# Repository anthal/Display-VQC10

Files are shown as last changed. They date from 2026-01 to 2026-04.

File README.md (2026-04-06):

# VQC10
DDR (WF) Punkt-Matrix-LED-Display VQC10 (Leiterplatte und Code)

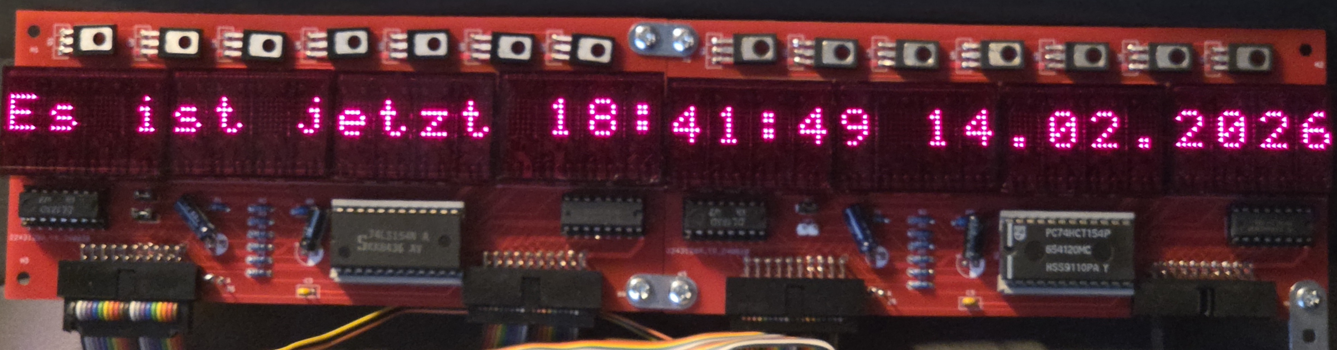
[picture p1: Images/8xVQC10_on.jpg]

Version 1

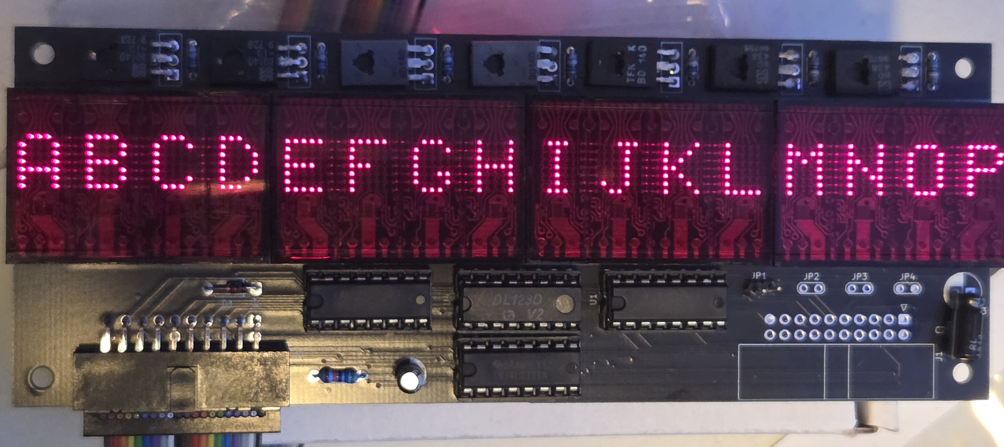
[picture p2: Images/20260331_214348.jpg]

Version 2

## Leiterplatte Version 2
### Platine
* Farbe der Platine V.1 auf den Bildern: rot
* Farbe der Platine V.2 auf den Bildern: schwarz
* KiCAD 9 Projekt
* Die Platinen sind nebeneinander anreihbar und es können bis zu 4 Stück kaskadiert werden.
* Ab der 2. Platine geht es mit Flachbandkabel zur nächsten Platine. 
* Jede Platine wird über eine eigene Leitung (SD4-SD7) aktiviert. Die Auswahl erfolgt über die 4 Jumper.

### Halbleiterbauelemente
* 4 x VQC 10 (4-Digit-Punkt-Matrix-LED-Displays) 
* 3 x 74LS138 (1-aus-8 Dekoder für Zeilen und 1-aus-16 Dekoder für Digits)
* 1 x 74LS123 (Schutzschaltung)
* 7 x BD140 (Zeilentreiber)

### Anschlüsse Leiterplatte Version 1
**An 20 pol. Steckerleiste:**
* ZD0 - ZD2 (3): Zeilendecoder (U1, 74HCT138)
* SD0 - SD3 (4): Stellendecoder (U2, U3, 2x 74HCT138)
* SD4 - SD7 (4): Selektierung der Stellendecoder über Jumper (Low-Aktiv)
* D1-D5 (5): Daten (Zeilen)

**Belegung der Anschlüsse:**
| Pin | Belegung | Raspberry Pi Pico | LC80ex | Pin LC80-Userport |
|-----|---|---|---|---|
| 1 | +5 V | +5 V | +5 V | 26 |
| 2 | +5 V | +5 V | +5 V | 25 |
| 3 | SD0 | GP20 | PB0 | 16 |
| 4 | ZD0 | GP15 | PA0 | 21 |
| 5 | SD1 | GP19 | PB1 | 18 |
| 6 | ZD1 | GP14 | PA1 | 19 |
| 7 | SD2 | GP18 | PB2 | 20 |
| 8 | ZD2 | GP12 | PA2 | 17 |
| 9 | SD3 | GP17 | PB3 | 22 |
| 10  | D1 | GP28 | PA3 | 7 |
| 11  | SD4 | GP16 | (Masse)| - |
| 12  | D2 | GP27 | PA4 | 9 |
| 13  | SD5 | GP10 | (Masse)| - |
| 14  | D3 | GP26 | PA5 | 11 |
| 15  | SD6 | GP9 | (Masse)| - |
| 16  | D4 | GP22 | PA6 | 13 |
| 17  | SD7 | GP8 | (Masse)| - |
| 18  | D5 | GP21 | PA7 | 15 |
| 19  | Masse | Masse | Masse  | 1 |
| 20  | Masse | Masse | Masse  | 2 |

### Selektion der 4 Leiterplatten
SD4-7 müssen zur Selektierung Low und der jeweilige Jumper geschlossen sein:
| Leiterplatte | Jumper | Pin (J1/J2) | Belegung | Port-Pin (Raspberry Pi Pico) |
|---|-----|----|-----|---|
| 1 | JP1 | 11 | SD4 | GP16 |
| 2 | JP2 | 13 | SD5 | GP10 |
| 3 | JP3 | 15 | SD6 | GP9 |
| 4 | JP4 | 17 | SD7 | GP8 |

**Leiterplatte 1:** 
* Jumper JP1 geschlossen
* Jumper JP2 geöffnet
* Jumper JP3 geöffnet
* Jumper JP4 geöffnet

**Leiterplatte 2:**
* Jumper JP1 geöffnet
* Jumper JP2 geschlossen
* Jumper JP3 geöffnet
* Jumper JP4 geöffnet

**Leiterplatte 3:**
* Jumper JP1 geöffnet
* Jumper JP2 geöffnet
* Jumper JP3 geschlossen
* Jumper JP4 geöffnet

**Leiterplatte 4:**
* Jumper JP1 geöffnet
* Jumper JP2 geöffnet
* Jumper JP3 geöffnet
* Jumper JP4 geschlossen

## Literatur
* Datenblatt
* Schaltungen aus der rfe

## Simulation
* Simulation von 1x VQC10 mit Z80 unter SimulIDE
* https://simulide.com/
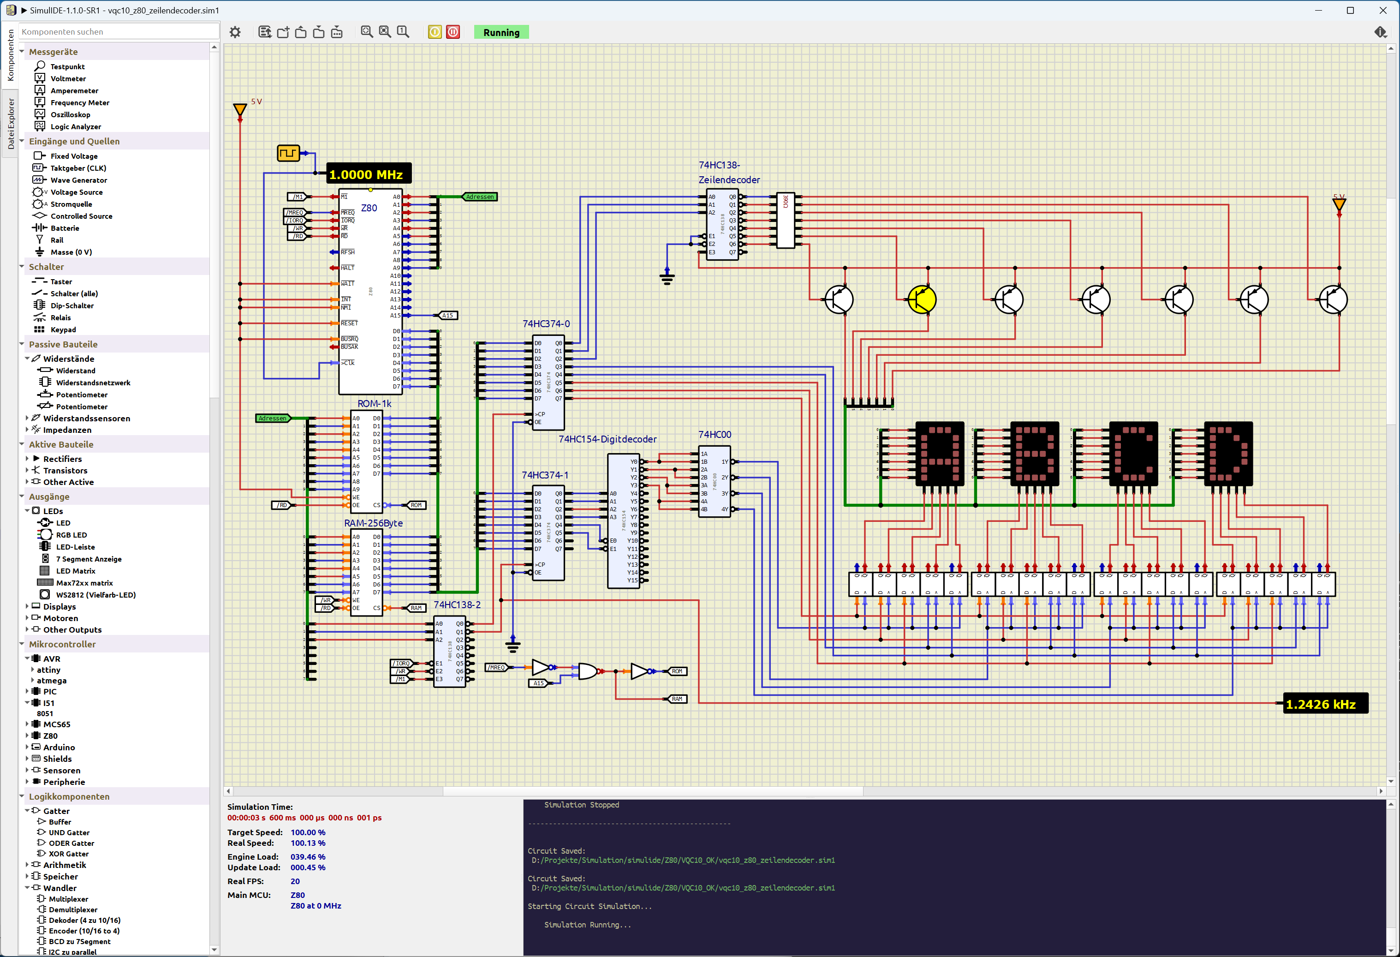
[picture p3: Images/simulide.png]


## Software
### Arduino Code
* Für den Raspberry Pi Pico
* auf Basis von https://github.com/versioduo/VQC10
* Vor Compilierung Example Datei und Files aus scr Verzeichnis in ein gemeinsames Verzeichnis verschieben

### Micropython Code
* Für den Raspberry Pi Pico

### Z80-Assembler
#### aZ80/RC2016-Computer
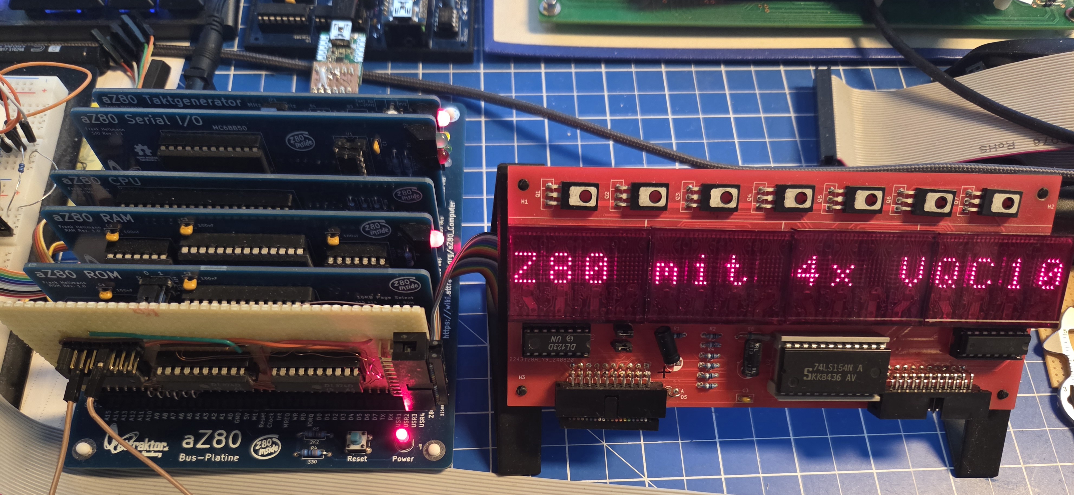
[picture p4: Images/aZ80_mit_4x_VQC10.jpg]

4x VQC10 am aZ80 Computer

Benutzte Entwicklungssoftware:
* "Small Computer-Monitor"
* https://smallcomputercentral.com/small-computer-monitor/

#### LC80ex
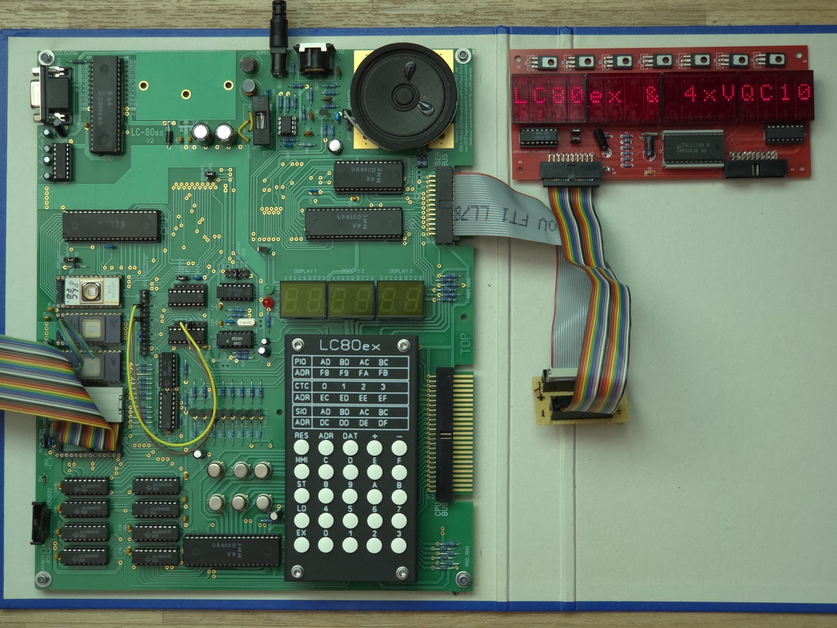
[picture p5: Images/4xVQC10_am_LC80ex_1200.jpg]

Test mit dem Nachbau des DDR-Platinen Computers LC80 

#### Z1013
ToDo

## Gehäuse
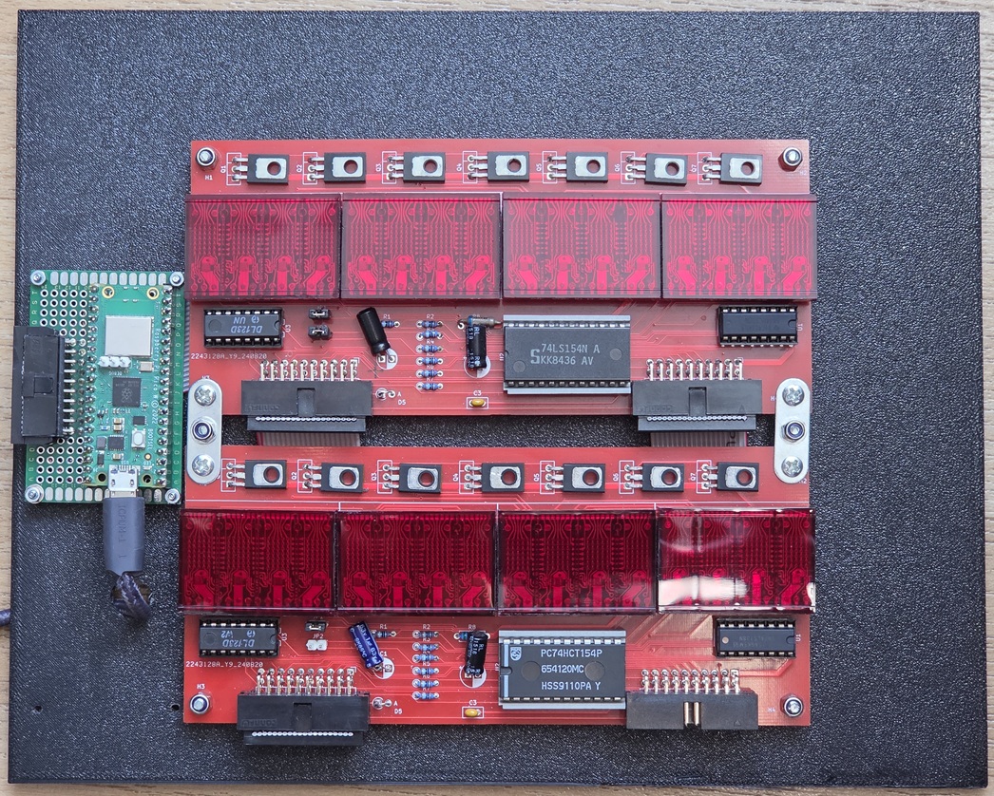
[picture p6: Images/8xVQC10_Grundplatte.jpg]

Grundplatte für IKEA Bilderrahmmen "VÄSTANHED 20x25 cm" mit Leiterplatten der Version 1
* STL Datei für 3D-Druck: "Gehäuse/2xVQC10_Grundplatte1.stl"

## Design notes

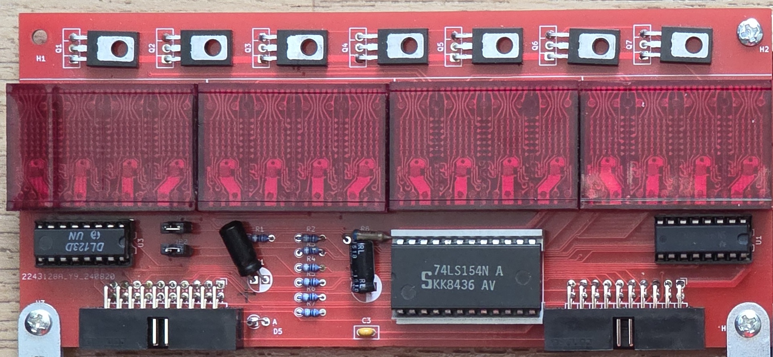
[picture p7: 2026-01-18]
Images/4xVQC10_off.jpg

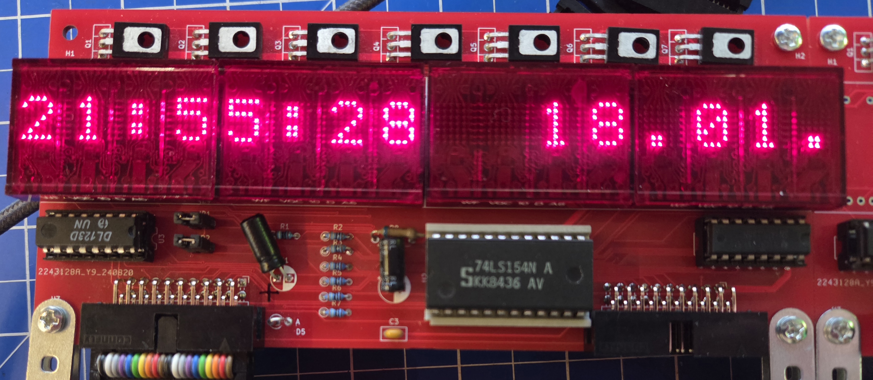
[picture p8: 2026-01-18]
Images/4xVQC10_on.jpg

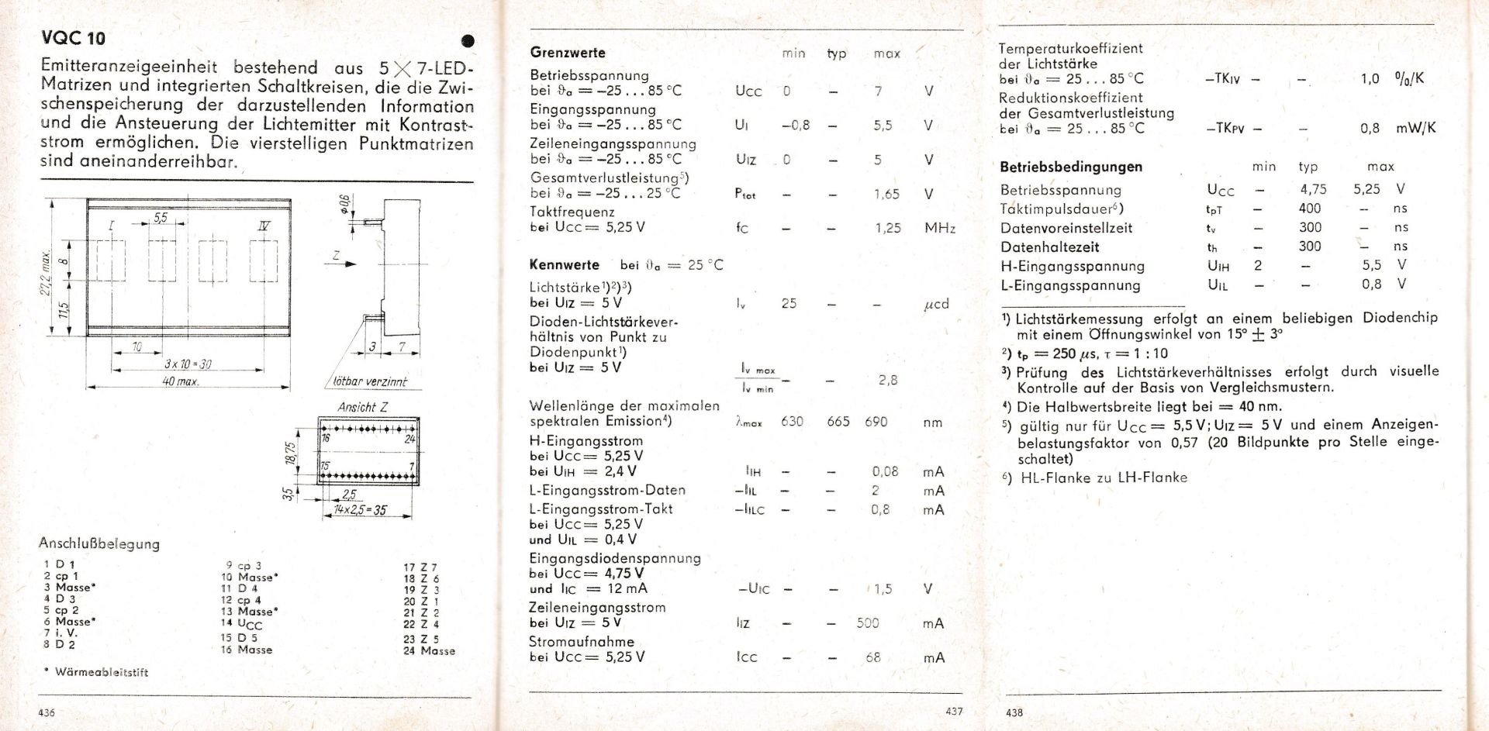
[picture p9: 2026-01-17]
Literatur/Datenblatt_VQC10.jpeg

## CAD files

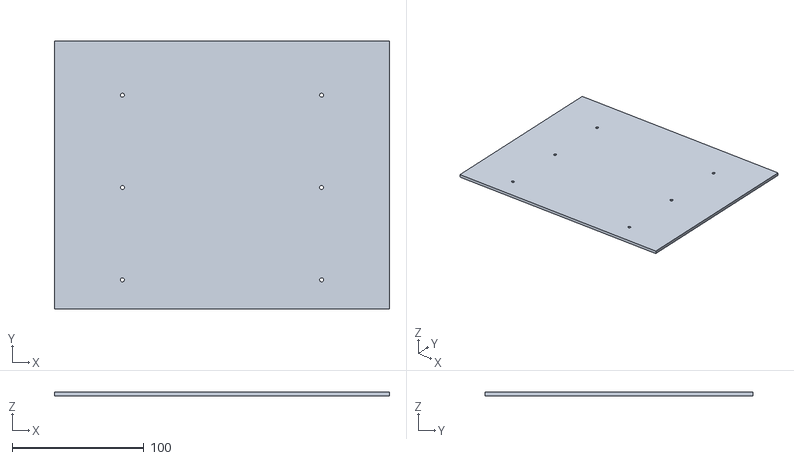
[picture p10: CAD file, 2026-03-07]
Gehäuse/2xVQC10 Grundplatte1.stl
254.0 x 203.0 x 3.00

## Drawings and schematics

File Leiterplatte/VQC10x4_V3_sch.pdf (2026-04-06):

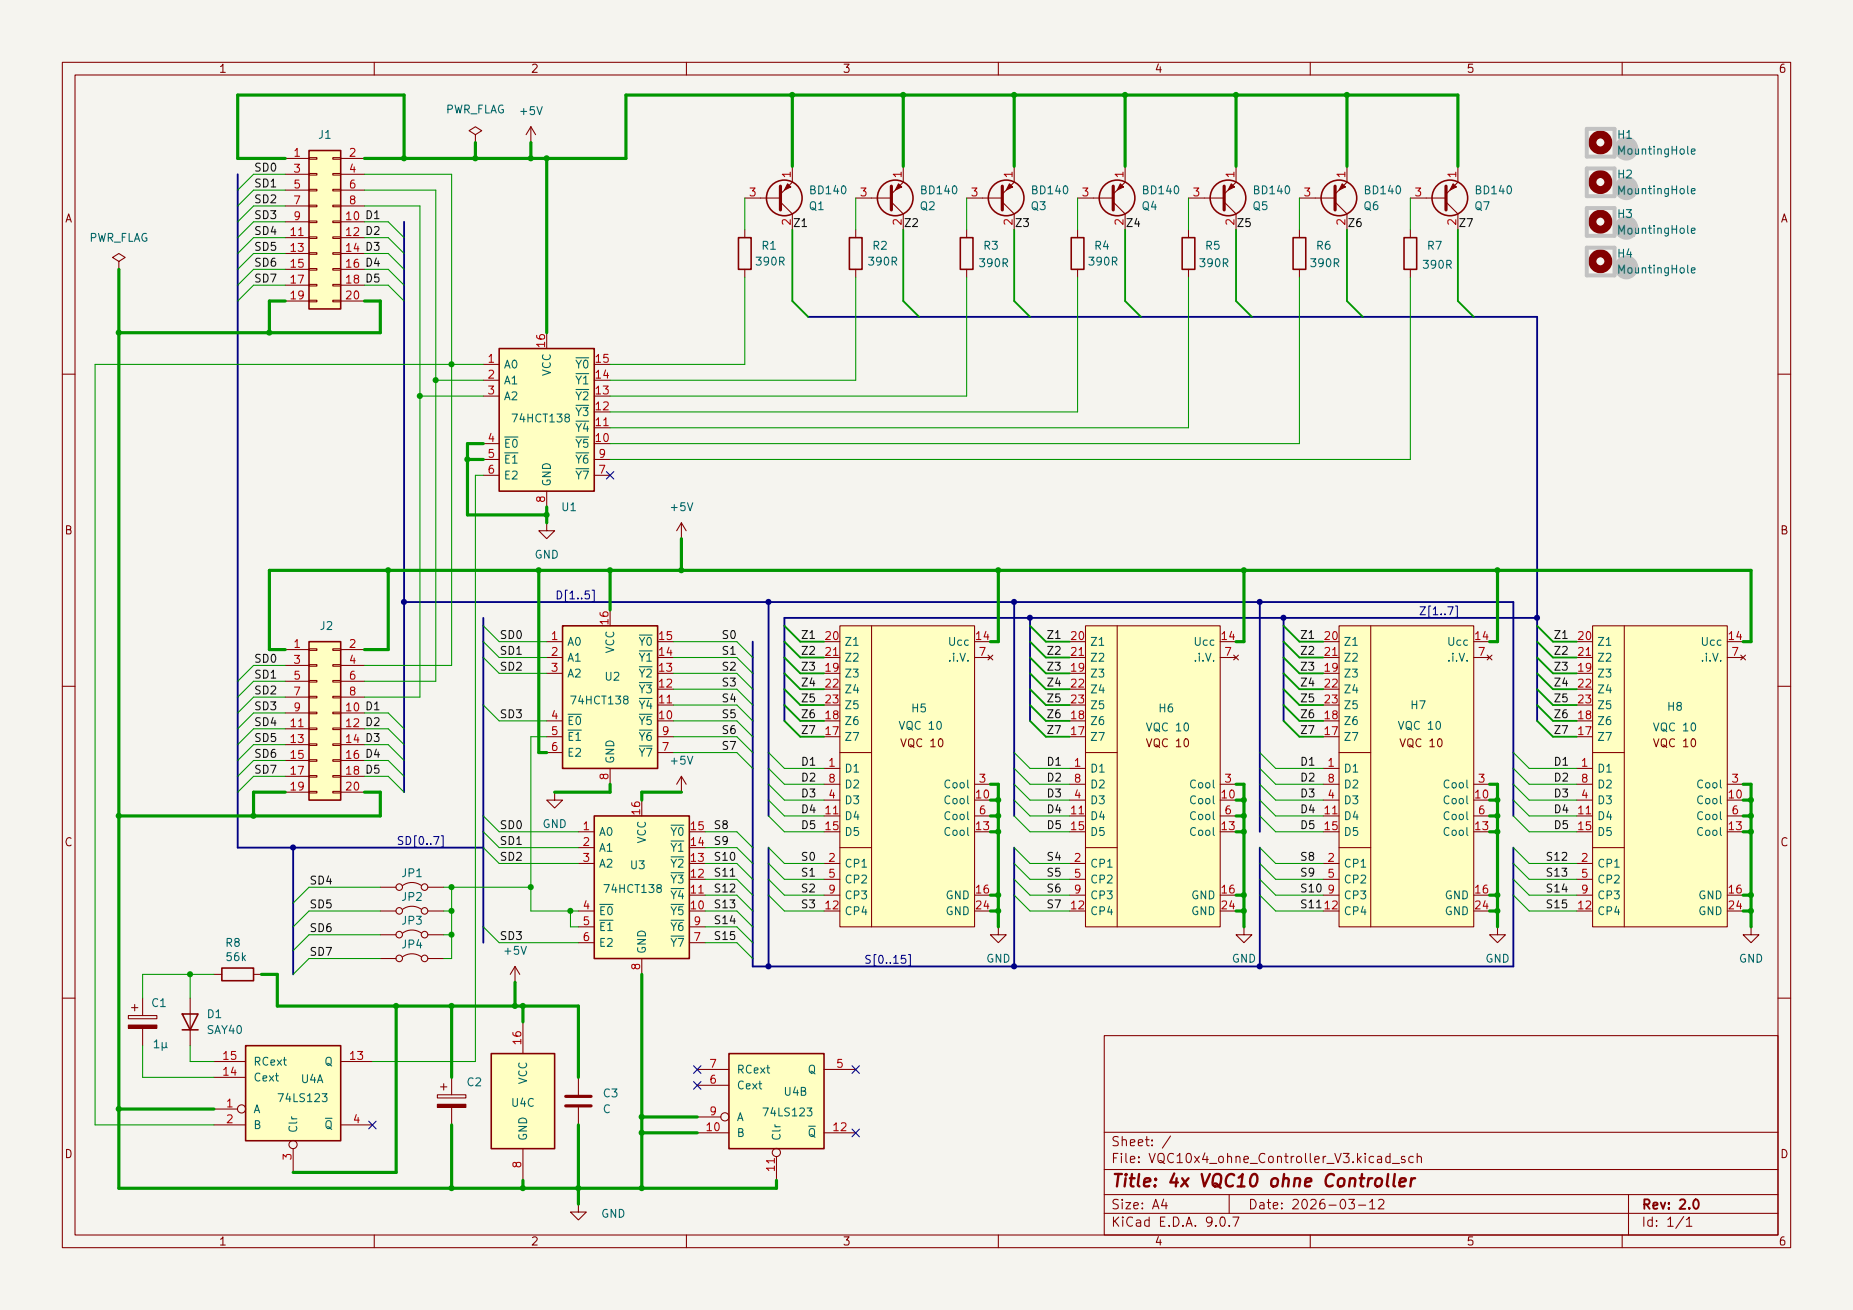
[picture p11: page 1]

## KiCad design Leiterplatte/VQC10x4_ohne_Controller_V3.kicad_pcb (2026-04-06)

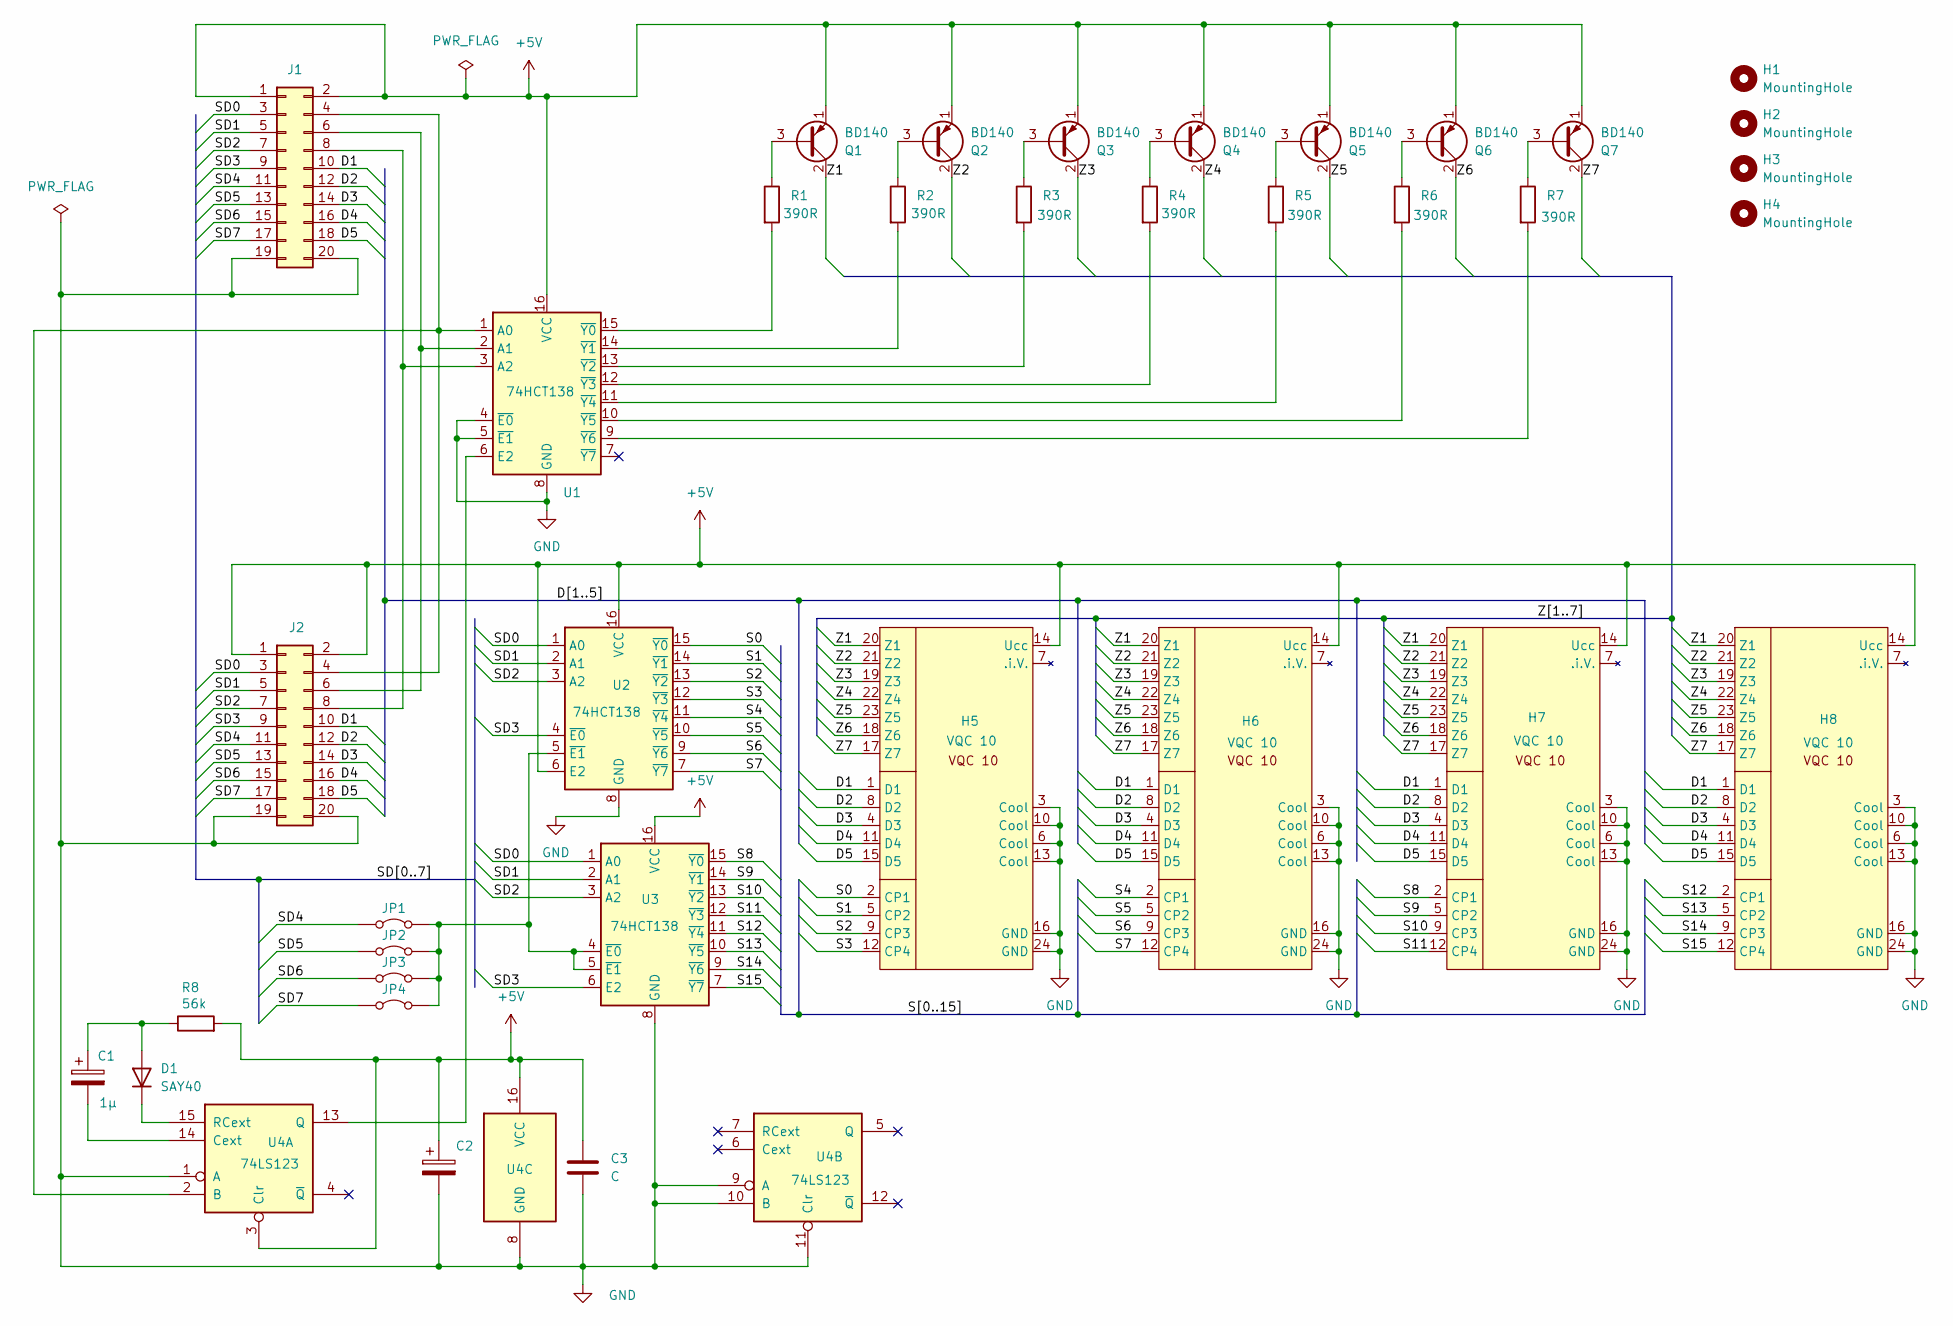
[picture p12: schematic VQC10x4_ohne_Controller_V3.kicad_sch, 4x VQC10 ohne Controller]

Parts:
C1: 1µ; CP_Radial_D5.0mm_P2.50mm
C2: C_Polarized; CP_Radial_D6.3mm_P2.50mm
C3: C; C_Disc_D5.0mm_W2.5mm_P2.50mm
D1: SAY40; D_A-405_P7.62mm_Horizontal
H1, H2, H3, H4: MountingHole; MountingHole_3.2mm_M3
H5, H6, H7, H8: VQC 10; VQC10
J1, J2: Conn_02x10_Odd_Even; IDC-Header_2x10_P2.54mm_Horizontal
JP1, JP2, JP3, JP4: Jumper_2_Bridged; TestPoint_2Pads_Pitch2.54mm_Drill0.8mm
Q1, Q2, Q3, Q4, Q5, Q6, Q7: BD140; TO-126-3_Vertical
R1, R2, R3, R4, R5, R6, R7: 390R; R_Axial_DIN0204_L3.6mm_D1.6mm_P5.08mm_Horizontal
R8: 56k; R_Axial_DIN0207_L6.3mm_D2.5mm_P7.62mm_Horizontal
U1, U2, U3: 74HCT138; DIP-16_W7.62mm_LongPads
U4: 74LS123; DIP-16_W7.62mm_LongPads

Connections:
+5V: C2.1, C3.1, H5.14 (Ucc), H6.14 (Ucc), H7.14 (Ucc), H8.14 (Ucc), J1.1, J1.2, J2.1, J2.2, Q1.1 (E), Q2.1 (E), Q3.1 (E), Q4.1 (E), Q5.1 (E), Q6.1 (E), Q7.1 (E), R8.2, U1.16 (VCC), U2.6 (E2), U2.16 (VCC), U3.16 (VCC), U4.3 (Clr), U4.16 (VCC)
/D1: H5.1 (D1), H6.1 (D1), H7.1 (D1), H8.1 (D1), J1.10, J2.10
/D2: H5.8 (D2), H6.8 (D2), H7.8 (D2), H8.8 (D2), J1.12, J2.12
/D3: H5.4 (D3), H6.4 (D3), H7.4 (D3), H8.4 (D3), J1.14, J2.14
/D4: H5.11 (D4), H6.11 (D4), H7.11 (D4), H8.11 (D4), J1.16, J2.16
/D5: H5.15 (D5), H6.15 (D5), H7.15 (D5), H8.15 (D5), J1.18, J2.18
/S0: H5.2 (CP1), U2.15 (~Y0)
/S1: H5.5 (CP2), U2.14 (~Y1)
/S2: H5.9 (CP3), U2.13 (~Y2)
/S3: H5.12 (CP4), U2.12 (~Y3)
/S4: H6.2 (CP1), U2.11 (~Y4)
/S5: H6.5 (CP2), U2.10 (~Y5)
/S6: H6.9 (CP3), U2.9 (~Y6)
/S7: H6.12 (CP4), U2.7 (~Y7)
/S8: H7.2 (CP1), U3.15 (~Y0)
/S9: H7.5 (CP2), U3.14 (~Y1)
/S10: H7.9 (CP3), U3.13 (~Y2)
/S11: H7.12 (CP4), U3.12 (~Y3)
/S12: H8.2 (CP1), U3.11 (~Y4)
/S13: H8.5 (CP2), U3.10 (~Y5)
/S14: H8.9 (CP3), U3.9 (~Y6)
/S15: H8.12 (CP4), U3.7 (~Y7)
/SD0: J1.3, J2.3, U2.1 (A0), U3.1 (A0)
/SD1: J1.5, J2.5, U2.2 (A1), U3.2 (A1)
/SD2: J1.7, J2.7, U2.3 (A2), U3.3 (A2)
/SD3: J1.9, J2.9, U2.4 (~E0), U3.6 (E2)
/SD4: J1.11, J2.11, JP1.1 (A)
/SD5: J1.13, J2.13, JP2.1 (A)
/SD6: J1.15, J2.15, JP3.1 (A)
/SD7: J1.17, J2.17, JP4.1 (A)
/Z1: H5.20 (Z1), H6.20 (Z1), H7.20 (Z1), H8.20 (Z1), Q1.2 (C)
/Z2: H5.21 (Z2), H6.21 (Z2), H7.21 (Z2), H8.21 (Z2), Q2.2 (C)
/Z3: H5.19 (Z3), H6.19 (Z3), H7.19 (Z3), H8.19 (Z3), Q3.2 (C)
/Z4: H5.22 (Z4), H6.22 (Z4), H7.22 (Z4), H8.22 (Z4), Q4.2 (C)
/Z5: H5.23 (Z5), H6.23 (Z5), H7.23 (Z5), H8.23 (Z5), Q5.2 (C)
/Z6: H5.18 (Z6), H6.18 (Z6), H7.18 (Z6), H8.18 (Z6), Q6.2 (C)
/Z7: H5.17 (Z7), H6.17 (Z7), H7.17 (Z7), H8.17 (Z7), Q7.2 (C)
GND: C2.2, C3.2, H5.3 (Cool), H5.6 (Cool), H5.10 (Cool), H5.13 (Cool), H5.16 (GND), H5.24 (GND), H6.3 (Cool), H6.6 (Cool), H6.10 (Cool), H6.13 (Cool), H6.16 (GND), H6.24 (GND), H7.3 (Cool), H7.6 (Cool), H7.10 (Cool), H7.13 (Cool), H7.16 (GND), H7.24 (GND), H8.3 (Cool), H8.6 (Cool), H8.10 (Cool), H8.13 (Cool), H8.16 (GND), H8.24 (GND), J1.19, J1.20, J2.19, J2.20, U1.4 (~E0), U1.5 (~E1), U1.8 (GND), U2.8 (GND), U3.8 (GND), U4.1 (A), U4.8 (GND), U4.9 (A), U4.10 (B), U4.11 (Clr)
unnamed: C1.1, D1.2 (A), R8.1
unnamed: D1.1 (K), U4.15 (RCext)
unnamed: J1.4, J2.4, U1.1 (A0), U4.2 (B)
unnamed: J1.6, J2.6, U1.2 (A1)
unnamed: J1.8, J2.8, U1.3 (A2)
unnamed: JP1.2 (B), JP2.2 (B), JP3.2 (B), JP4.2 (B), U2.5 (~E1), U3.4 (~E0), U3.5 (~E1)
unnamed: Q1.3 (B), R1.1
unnamed: Q2.3 (B), R2.1
unnamed: Q3.3 (B), R3.1
unnamed: Q4.3 (B), R4.1
unnamed: Q5.3 (B), R5.1
unnamed: Q6.3 (B), R6.1
unnamed: Q7.3 (B), R7.1
unnamed: U1.6 (E2), U4.13 (Q)
unnamed: R1.2, U1.15 (~Y0)
unnamed: R2.2, U1.14 (~Y1)
unnamed: R3.2, U1.13 (~Y2)
unnamed: R4.2, U1.12 (~Y3)
unnamed: R5.2, U1.11 (~Y4)
unnamed: R6.2, U1.10 (~Y5)
unnamed: R7.2, U1.9 (~Y6)
unnamed: C1.2, U4.14 (Cext)

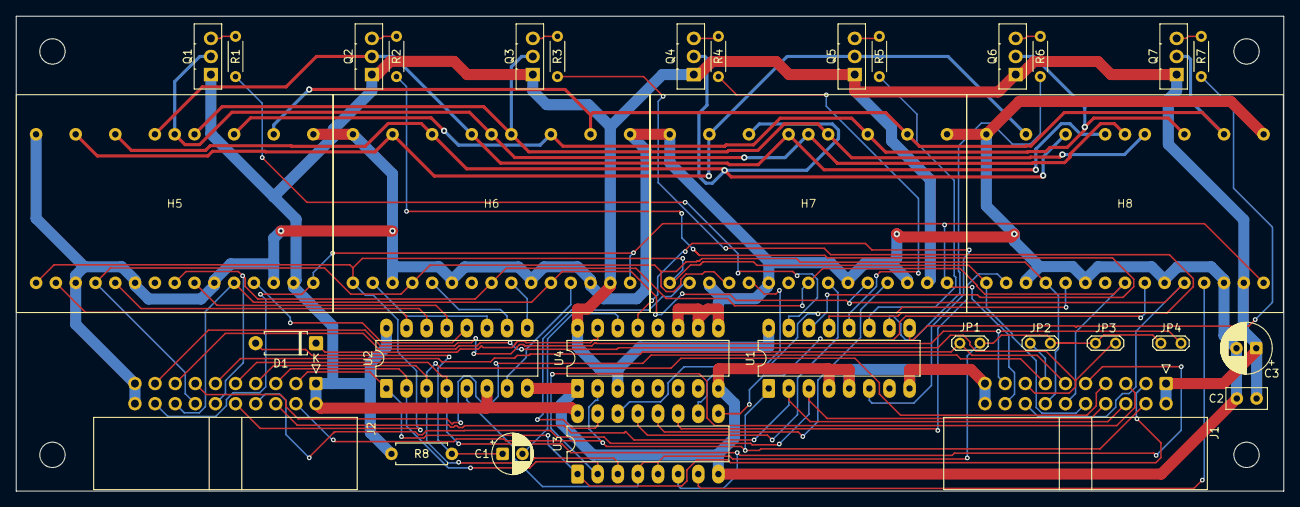
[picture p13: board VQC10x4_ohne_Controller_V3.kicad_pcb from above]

Board: 2 copper layers, 160.0 x 59.9 mm, 37 parts (0 on the bottom side), 60 nets.

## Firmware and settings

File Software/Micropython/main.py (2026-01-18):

# Speichern und Durchschalten der Daten pro Stelle mit der L/H Flanke des Stellentakts
#

# VQC 10 einstellig
# Mit 74HCT138 als Zeilendecoder
# Mit 74HCT154 als Spaltendecoder

import time
from machine import Pin
from machine import Timer
from bitmap5x7 import getBitmap

# Zeilen Pins:
pin_z0 = 15
pin_z1 = 14
pin_z2 = 12
pin_z3 = 8  # Zur (De-)Aktivierung des Zeilendecoders 

# Spalten Pins:
pin_d1 = 28
pin_d2 = 27
pin_d3 = 26
pin_d4 = 22
pin_d5 = 21

# Takt Pins (Stellen):
pin_cp1 = 20
pin_cp2 = 19
pin_cp3 = 18
pin_cp4 = 17
pin_cp5 = 16
pin_cp6 = 10
# pin_cp7 = 9

# Zeilen:
#z = [0,0,0,0,0,0,0]
z = [1,1,1,1]
z[0] = Pin(pin_z0, Pin.OUT, value=0)    # create output pin 
z[1] = Pin(pin_z1, Pin.OUT, value=0)    # create output pin
z[2] = Pin(pin_z2, Pin.OUT, value=0)    # create output pin
z[3] = Pin(pin_z3, Pin.OUT, value=0)    # create output pin


# Spaltendaten:
d = [0,0,0,0,0]
d[0] = Pin(pin_d1, Pin.OUT, value=0)    # create output pin 
d[1] = Pin(pin_d2, Pin.OUT, value=0)    # create output pin
d[2] = Pin(pin_d3, Pin.OUT, value=0)    # create output pin
d[3] = Pin(pin_d4, Pin.OUT, value=0)    # create output pin
d[4] = Pin(pin_d5, Pin.OUT, value=0)    # create output pin

# Takte (Stellen):
cp = [0,0,0,0,0,0,0]
cp[0] = Pin(pin_cp1, Pin.OUT)    # create output pin 
cp[1] = Pin(pin_cp2, Pin.OUT)    # create output pin
cp[2] = Pin(pin_cp3, Pin.OUT)    # create output pin
cp[3] = Pin(pin_cp4, Pin.OUT)    # create output pin
cp[4] = Pin(pin_cp5, Pin.OUT)    # create output pin
cp[5] = Pin(pin_cp6, Pin.OUT)    # create output pin
#cp[6] = Pin(pin_cp7, Pin.OUT)    # create output pin


#text1 = "ABCDEFGHIJKLMNOPQRSTUVWXYZÄÖÜ"
#text2 = "abcdefghijklmnopqrstuvwxyzäöüß"
#text3 = "1234567890!§$%&/()=?[],.-;:_<>|@"
#text_in = "x+x+x+x+x+x+"
#text_in = text1 + text2 + text3
text = "ABCD"
#text = "abcd"
#print("Auf VQC 10:", text)
zeile_alt = 0
i = 0
zeile = 0

def zeilen_decoder(i):
    # Deaktivierung der Ausgänge ueber 74HCT138 (E2):
    z[3].value(0)
    #z[0].value(1)
    #z[1].value(1)
    #z[2].value(1)
    
    a = i & 1
    b = (i & 2) >> 1
    c = (i & 4) >> 2
    
    z[0].value(a)
    z[1].value(b)
    z[2].value(c)
    
    # Aktivierung der Ausgänge:
    z[3].value(1)
    #print(i,a,b,c)
    
    
def digit_decoder(i):
    cp[5].value(0)
    #cp[6].value(0)

    a = i & 1
    b = (i & 2) >> 1
    c = (i & 4) >> 2
    d = (i & 8) >> 3
    #e = (i & 16) >> 4
    cp[0].value(a)
    cp[1].value(b)
    cp[2].value(c)
    cp[3].value(d)
    # Aktivierung der Ausgänge:
    cp[4].value(0)
    # Deaktivierung der Ausgänge:
    cp[4].value(1)
    #print(i,a,b,c,d)
    
    
def timer_tick(text):
    global zeile
    
    # Alte Zeile deaktivieren (setze Dekoder auf Zeile 8):
    #z[zeile].value(1)
    #z[0].value(1)
    #z[1].value(1)
    #z[2].value(1)
    # Zeilendecoder dunkel schalten:
    z[3].value(0)
    
    zeile += 1
    if zeile == 7:
        zeile = 0
    #print(zeile)
        
    # Pro Stelle/Digit:
    for digit in range(len(text)):
        bitmap = getBitmap(ord(text[digit]))
        #print(digit, bitmap)
        
        # Pro Spalte:
        for spalte in range(5):
            bit = bitmap[spalte] & (1 << zeile)
            d[spalte].value(bit)

        # Daten fuer aktuelle Stelle uebernehmen:
        digit_decoder(digit)
        
    # Aktuelle Zeile aktivieren:
    #z[zeile].value(0)
    zeilen_decoder(zeile)
    

tim = Timer(freq=200, mode=Timer.PERIODIC, callback=lambda t:timer_tick(text))
# freq=500
counter = 0
while True:
    zeit = time.localtime(time.time())
    #print(zeit)
    text = "{0:02d}.{1:02d}.  {3:02d}:{4:02d}:{5:02d}".format(zeit[2],zeit[1],zeit[0],zeit[3],zeit[4],zeit[5])    
    time.sleep(1)
    
    

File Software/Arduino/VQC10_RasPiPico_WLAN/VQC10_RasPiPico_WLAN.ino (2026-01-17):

#include <WiFi.h>
#include <NTPClient.h>
#include <WiFiUdp.h>
#include <TimeLib.h>        // Michael Margolis
#include <RP2040_RTC.h>     // Khoi Hoang (optional, für persistente RTC)
#include "VQC10.h"

// WLAN
const char* ssid = "anth-0";
const char* password = "anthal-17!";

// NTP
WiFiUDP ntpUDP;
NTPClient timeClient(ntpUDP, "pool.ntp.org", 3600, 60000);  // CET

datetime_t dt;  // RTC-Datentyp

static VQC10<> LED({
  {20, 19, 18, 17, 16, 10},     // Digits über Dekoder - d:\Projekte\Displays\VQC 10\Arduino\VQC10-main\src\Font5x7.cpp
  {28, 27, 26, 22, 21}, // Spalten
  {15, 14, 12, 8},      // Zeilen über Dekoder: Pin 8 (De-)Aktivierung des Zeilendecoders 
});

//static const char text[] = "1234567890123456";
//String text =   "VQC10 Terminal  ";
String text =   "";
//String text = "Andreas Thalmann und Rosi --------------";         // Speichert empfangene Zeichen
bool stringComplete = false;     // Flag für vollständige Zeile

void setup() {
  // Init:
  LED.begin();

  Serial.begin(115200);
  delay(1000);

  // WLAN & NTP
  WiFi.begin(ssid, password);
  while (WiFi.status() != WL_CONNECTED) {
    delay(500);
    Serial.print(".");
  }
  Serial.println("\nWLAN OK");

    timeClient.begin();
  timeClient.update();
  unsigned long epoch = timeClient.getEpochTime();

  // Epoch zu datetime_t konvertieren
  time_t rawtime = epoch;
  struct tm *ti = gmtime(&rawtime);
  dt.year  = ti->tm_year + 1900;
  dt.month = ti->tm_mon + 1;
  dt.day   = ti->tm_mday;
  dt.dotw  = ti->tm_wday;
  dt.hour  = ti->tm_hour;
  dt.min   = ti->tm_min;
  dt.sec   = ti->tm_sec;

  // RTC initialisieren & setzen
  rtc_init();
  rtc_set_datetime(&dt);
  char datumStr[64];
  strftime(datumStr, sizeof(datumStr), "%Y.%m.%d %H:%M:%S", ti);
  Serial.println("RTC gesetzt: " + String(datumStr));

  WiFi.disconnect();

  Serial.printf("Start VQC10\n");
}

void loop() {
  static unsigned long usec{};
  static uint16_t count{};
  char buffer[64];

  // RTC lesen
  datetime_t now;
  rtc_get_datetime(&now);
  //Serial.printf("Uhrzeit: %04d.%02d.%02d %02d:%02d:%02d\n", now.year, now.month, now.day, now.hour, now.min, now.sec);
  sprintf(buffer, "%02d:%02d:%02d  %02d.%02d.", now.hour, now.min, now.sec, now.day, now.month);
  text = buffer;

  //Serial.printf(text);
  count = 0;
  //if ((unsigned long)(micros() - usec) > 150UL * 1000) {   
  // laengere Scrollzeit:   
  if ((unsigned long)(micros() - usec) > 150UL * 2000) {      
    usec = micros();

    // für alle 16 Stellen:
    //Serial.printf("count: %1d - %c %c %c %c\n", count, text[count + 0], text[count + 1], text[count + 2], text[count + 3]);
    for (uint8_t i = 0; i < 16; i++) {
      LED.show(i, text[count + i]);
    }
      
    count++;
    if (count + 16 == sizeof(text))
      count = 0;
  }
  //delay(1000);
  LED.loop();  
  
}

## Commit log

2026-01-17 Erste Commit
    [4xVQC10.kicad_pcb, 4xVQC10.kicad_sch]
2026-01-18 Update Leiterplatten, Bild und Literatur
    [4xVQC10.kicad_pcb, 4xVQC10.kicad_sch, VQC10x4_ohne_Controller_KiCad9.kicad_pcb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]
2026-01-18 Update Schaltplan + PDF
    [VQC10x4_ohne_Controller_KiCad9.kicad_sch]
2026-01-18 CHG: Bilderverzeichnis geändert und in readme eingefügt
2026-01-18 CHG: Neuordnung der Arduino Files
2026-01-22 CHG: Optimierung der Beispiele
2026-01-22 CHG: WLAN Passwort und SSID in extra Datei auslagern
2026-01-23 ADD: mehr Infos auf VQC10 und Kapselung Displayausgabe
2026-02-28 ADD: Z80-Assembler Code
2026-03-04 ADD: Assembler Code für den LC80ex
2026-03-05 CHG: Verbesserung der Deaktivierung des Stellendekoders
2026-03-06 CHG: Formatierung der Readme repariert
2026-03-07 ADD: 3D-Grundplatte + Bild
    [2xVQC10 Grundplatte1.stl]
2026-04-06 UPD: Neue Leiterplattenversion
    [VQC10x4_ohne_Controller_KiCad9.kicad_pcb, VQC10x4_ohne_Controller_V3.kicad_pcb, VQC10x4_ohne_Controller_V3.kicad_sch]
2026-04-06 CHG: Anpassung der Simulation an Leiterplatte V2
